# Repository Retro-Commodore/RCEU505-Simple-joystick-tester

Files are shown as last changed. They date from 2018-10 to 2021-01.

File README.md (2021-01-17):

# RCEU505 - Simple Joysticktester
A Simple Joystick Tester as a DIY for Commodore/Atari style digital joystick

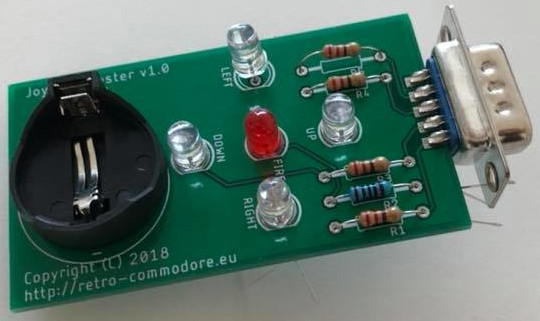
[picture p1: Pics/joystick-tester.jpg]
Joystick Tester unsoldered image


Read the document for which resistor values to use for which color LED.  
The LED's can be generic ones from eBay, so resistor values might not be right for your choice.  

Shopping list
* 5x resistors
* 5x 5mm round LEDs
* 1x 9 pin sub-d male
* 1x CR2032 socket
* 1x CR20xx battery (CR2016/CR2025/CR2032 have been tested in the sockets)

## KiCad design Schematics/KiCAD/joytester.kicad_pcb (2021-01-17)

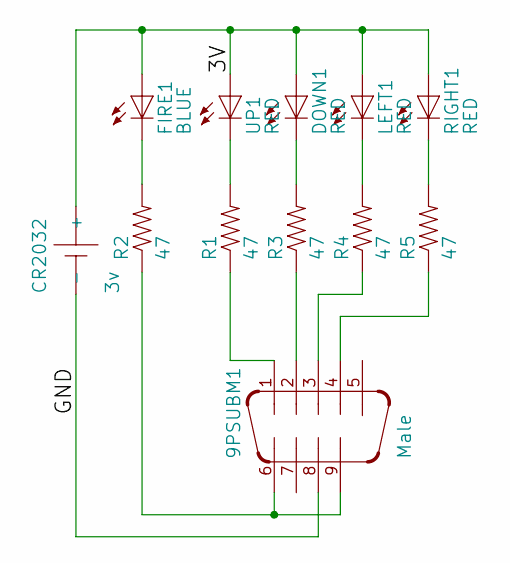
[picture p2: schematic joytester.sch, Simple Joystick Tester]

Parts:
9PSUBM1: Male; M09D
CR2032: 3v; SN2032
DOWN1: RED; LED5MM
FIRE1: BLUE; LED5MM
LEFT1: RED; LED5MM
R1, R2, R3, R4, R5: 47; 0207_12
RIGHT1: RED; LED5MM
UP1: RED; LED5MM

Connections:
/3V: CR2032.+, DOWN1.A, FIRE1.A, LEFT1.A, RIGHT1.A, UP1.A
/GND: 9PSUBM1.8, CR2032.-
unnamed: 9PSUBM1.1, R1.1
unnamed: 9PSUBM1.2, R3.1
unnamed: 9PSUBM1.3, R4.1
unnamed: 9PSUBM1.4, R5.1
unnamed: 9PSUBM1.6, 9PSUBM1.9, R2.1
unnamed: DOWN1.K (C), R3.2
unnamed: FIRE1.K (C), R2.2
unnamed: LEFT1.K (C), R4.2
unnamed: R1.2, UP1.K (C)
unnamed: R5.2, RIGHT1.K (C)

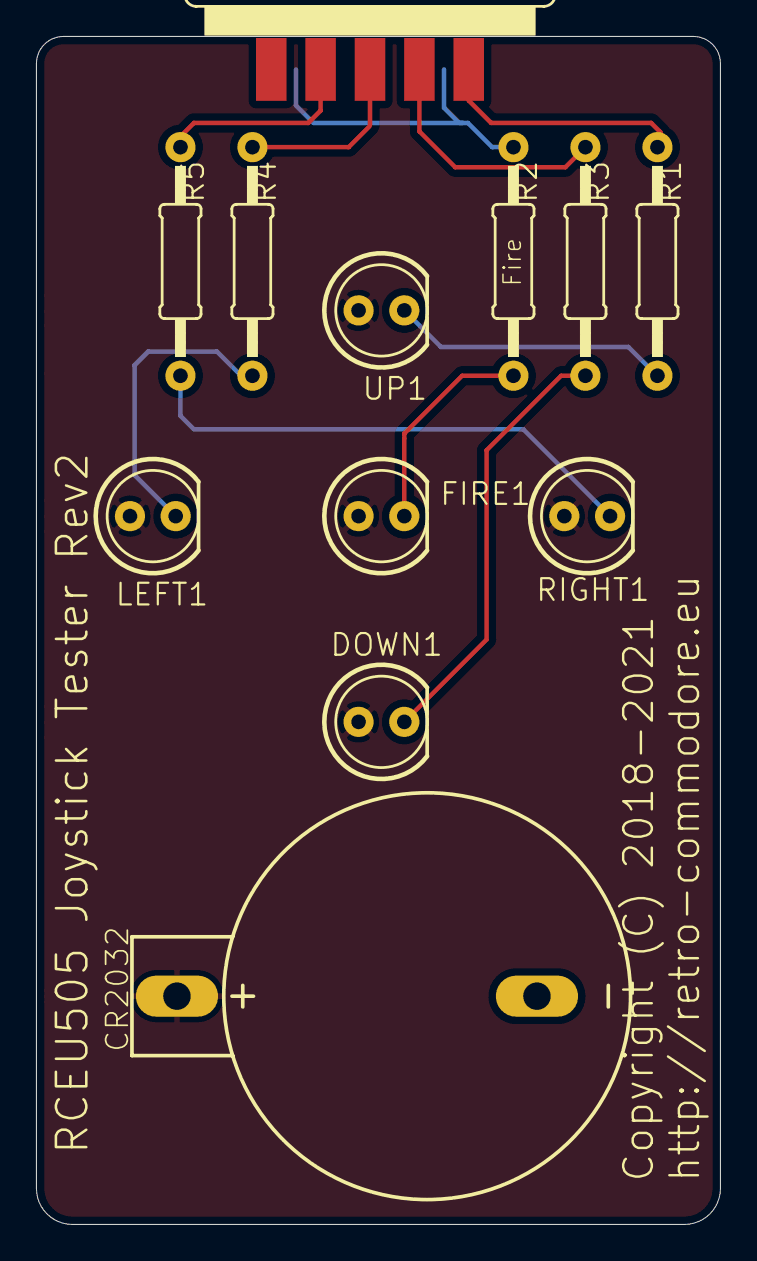
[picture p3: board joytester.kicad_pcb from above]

Board: 2 copper layers, 38.0 x 66.0 mm, 12 parts (0 on the bottom side), 12 nets.

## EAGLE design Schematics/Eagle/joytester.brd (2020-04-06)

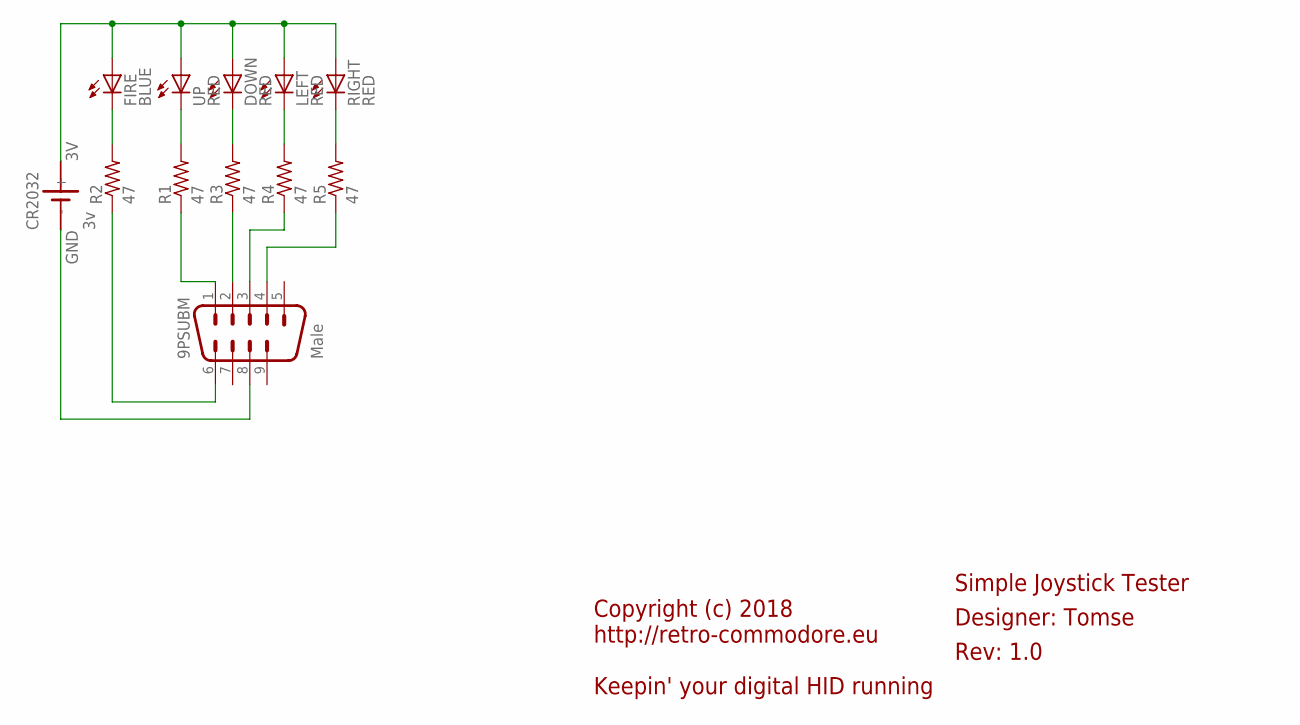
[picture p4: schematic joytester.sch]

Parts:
9PSUBM: Male; M09D
CR2032: 3v; SN2032
DOWN: RED; LED5MM
FIRE: BLUE; LED5MM
LEFT: RED; LED5MM
R1, R2, R3, R4, R5: 47; 0207/12
RIGHT: RED; LED5MM
UP: RED; LED5MM

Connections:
3V: CR2032.+, DOWN.A, FIRE.A, LEFT.A, RIGHT.A, UP.A
DOWN: 9PSUBM.2, R3.1
GND: 9PSUBM.8, CR2032.-
unnamed: FIRE.K (C), R2.2
unnamed: LEFT.K (C), R4.2
unnamed: R5.2, RIGHT.K (C)
unnamed: R1.2, UP.K (C)
unnamed: DOWN.K (C), R3.2
unnamed: 9PSUBM.6, R2.1
unnamed: 9PSUBM.3, R4.1
unnamed: 9PSUBM.4, R5.1
UP: 9PSUBM.1, R1.1

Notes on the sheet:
Copyright (c) 2018 http://retro-commodore.eu Keepin' your digital HID running
Simple Joystick Tester
Designer: Tomse
Rev: 1.0

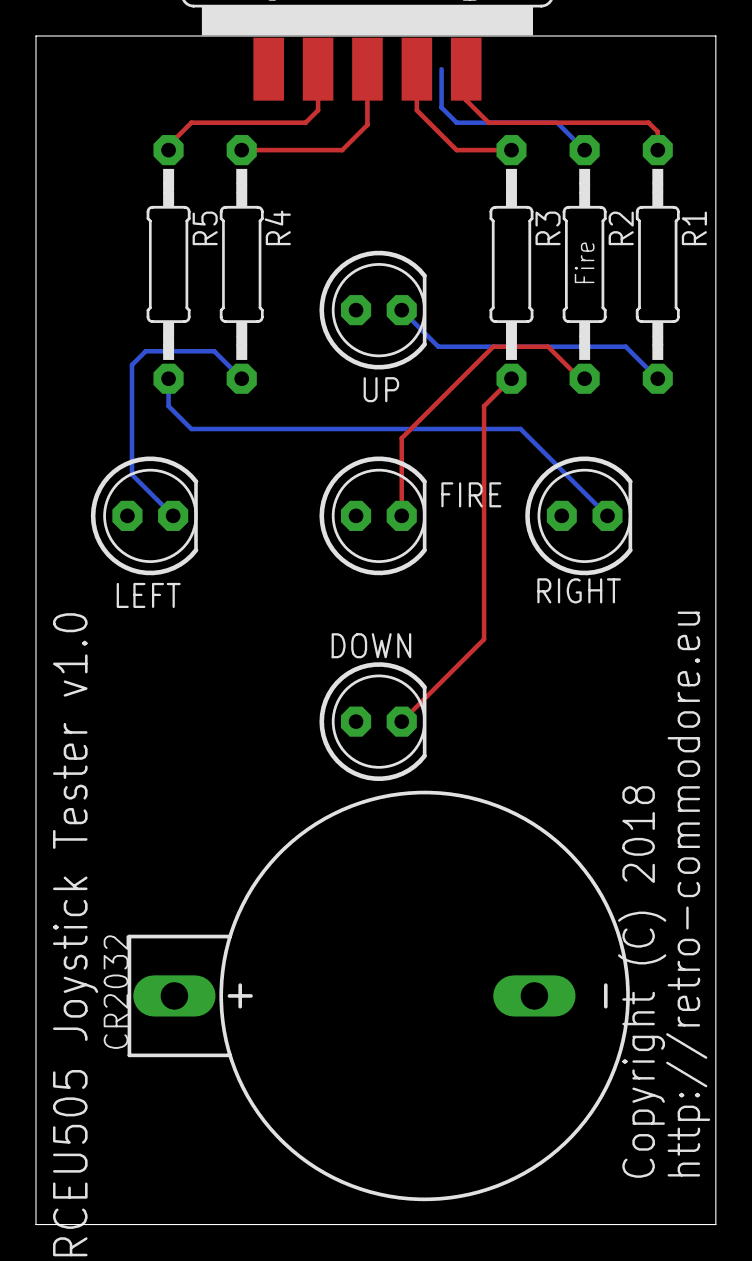
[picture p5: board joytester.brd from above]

Board: 2 copper layers, 37.8 x 66.0 mm, 12 parts (0 on the bottom side), 12 nets.

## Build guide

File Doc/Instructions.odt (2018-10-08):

Joystick Tester v1.0

DIY Instructions

http://retro-commodore.eu

Congratulations with your new Simple Joystick Tester,

and thank you for supporting http://retro-commodore.eu.

LED’s are inserted as the image, long leg-anode- at the rounded edge, and short leg -cathode- at the flat edge.

Packing List

5 x LEDs

5 x Resistors

1 x PCB

1 x CR20xx Battery

1 x Battery socket

1 x 9P Male d-sub connector

The LED’s with the battery socket and

connector are the ones that need to be placed correctly.

The resistors doesn’t matter which way they are turned,

but they’ll look best if the color codes are placed to one

side.

Resistor values – Select the value of the resistor that matches the color.

LED Color | Value | Color codes
Blue | 47ohm | Yellow, purple, black
Green | 47ohm | Yellow, purple, black
Red | 100ohm | Brown, black, black
Yellow | 100ohm | Brown, black, black
White | 220ohm | Red, red, brown

Resistor placements

Function | Resistor
Up | R1
Down | R3
Fire | R2
Left | R4
Right | R5

Battery socket takes CR2016, CR2025 and CR2032 batteries.

Joystick Tester v1.0

DIY Instructions

http://retro-commodore.eu

Congratulations with your new Simple Joystick Tester,

and thank you for supporting http://retro-commodore.eu.

LED’s are inserted as the image, long leg-anode- at the rounded edge, and short leg -cathode- at the flat edge.

Packing List

5 x LEDs

5 x Resistors

1 x PCB

1 x CR20xx Battery

1 x Battery socket

1 x 9P Male d-sub connector

The LED’s with the battery socket and

connector are the ones that need to be placed correctly.

The resistors doesn’t matter which way they are turned,

but they’ll look best if the color codes are placed to one

side.

Resistor values – Select the value of the resistor that matches the color.

LED Color | Value | Color codes
Blue | 47ohm | Yellow, purple, black
Green | 47ohm | Yellow, purple, black
Red | 100ohm | Brown, black, black
Yellow | 100ohm | Brown, black, black
White | 220ohm | Red, red, brown

Resistor placements

Function | Resistor
Up | R1
Down | R3
Fire | R2
Left | R4
Right | R5

Battery socket takes CR2016, CR2025 and CR2032 batteries.

Version 1.01 (C) 2018 http://retro-commodore.eu 2018-06-13

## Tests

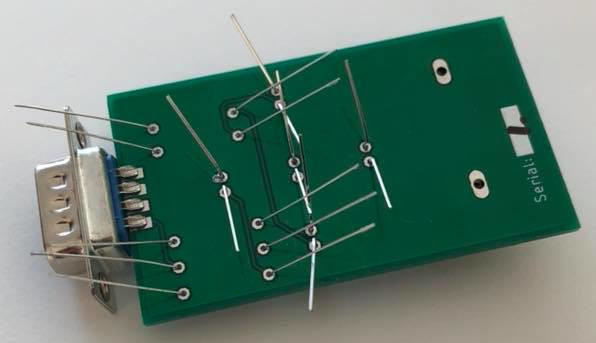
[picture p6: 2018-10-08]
Pics/joystick-tester2.jpg

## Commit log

2020-04-06 cosmetic changes
    [joytester.brd]
2020-04-06 Fixing dirnaming
    [joytester.brd, joytester.sch]
2020-09-27 moved to kicad, while adding support for joystick button nr 2
    [joytester-B_Mask.gbr, joytester-B_Paste.gbr, joytester-B_SilkS.gbr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]
2020-09-27 Clean up
    [joytester-B_Mask.gbr, joytester-B_Paste.gbr, joytester-B_SilkS.gbr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]
2021-01-17 Cosmetic changed - added 3d components to 3d view
    [joytester.kicad_pcb]

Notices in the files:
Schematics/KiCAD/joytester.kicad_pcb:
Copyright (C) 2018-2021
